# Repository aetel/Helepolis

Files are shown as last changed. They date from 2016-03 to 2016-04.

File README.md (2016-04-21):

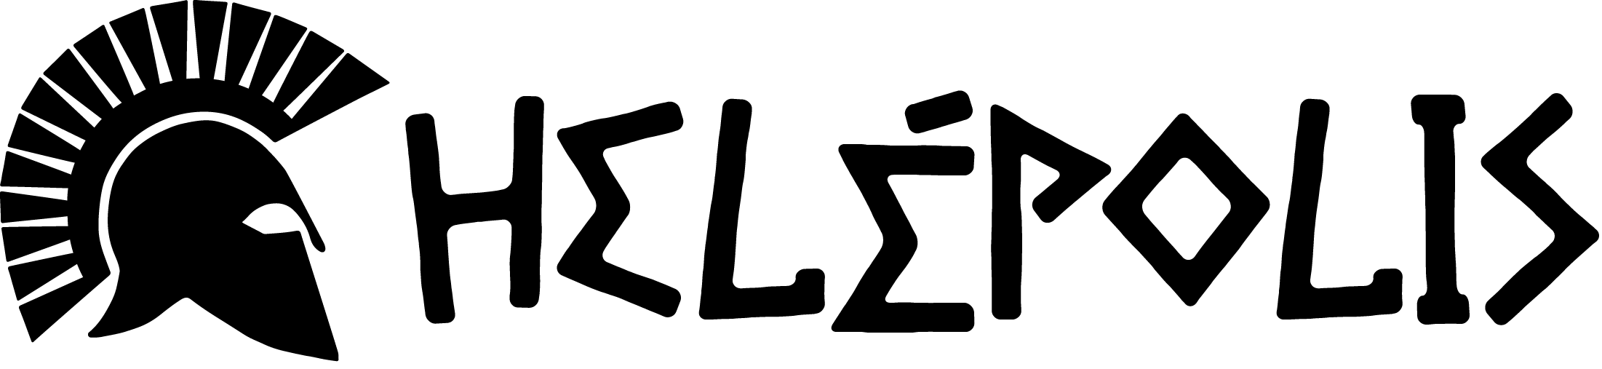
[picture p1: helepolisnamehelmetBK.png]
Helepolis


Helepolis is an **educative** robot for those who want to have their **first contact** with robotics.

It's based around the Arduino platform, using an Arduino Nano as its brain.
It can be programmed to complete numerous tasks such as line following and sumo fighting.

---
### The machine includes:
* An Arduino Nano with ATMega 328p
* SHARP Distance Sensor
* 5 Reflective IR Sensors
* Differential Traction with 2 Pololu Micromotors
* Bluetooth module.
* 2 WS2812 RGB LED
* 4 5mm led
* I2C or SPI Expansion Module Port (intended use is for an ADXL345 3-axis accelerometer)
* Buzzer
* A few switches for general use

---
### In this repository you will find:
* EagleCAD project
<br>&nbsp;&nbsp;Includes the schematic and the PCB files
* TestCode
<br>&nbsp;&nbsp;A program to check all the sensors and actuators are working fine
* ExampleCode
<br>&nbsp;&nbsp;Line follower and sumo bot example program
* Assembly manuals
<br>&nbsp;&nbsp;Guided assembly manuals in English and Spanish
* BoM
<br>&nbsp;&nbsp;Bill of Materials used for the robot

---
### Android app:
You can download the app to control the robot at [Google Play](https://play.google.com/store/apps/details?id=aetel.helepolis), though you may be interested in building or modifying the code available in this repository.

---


Helepolis and its surrounding materials are published under [CC BY-SA 4.0](https://creativecommons.org/licenses/by-sa/4.0/)

Helepolis was designed by [Pablo dMM](https://github.com/PabloDMM "Pablo dMM") for Telecom Electronics Association [AETEL](http://aetel.io), based at the Campus Sur of [Universidad Politécnica de Madrid](http://upm.es).

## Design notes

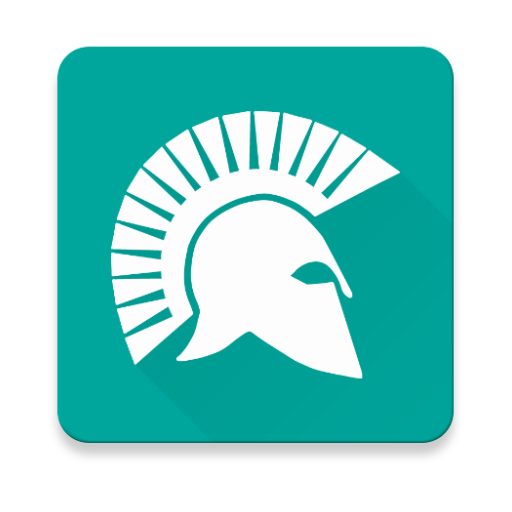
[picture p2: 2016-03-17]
Android project/Helepolis/ic_launcher-web.png

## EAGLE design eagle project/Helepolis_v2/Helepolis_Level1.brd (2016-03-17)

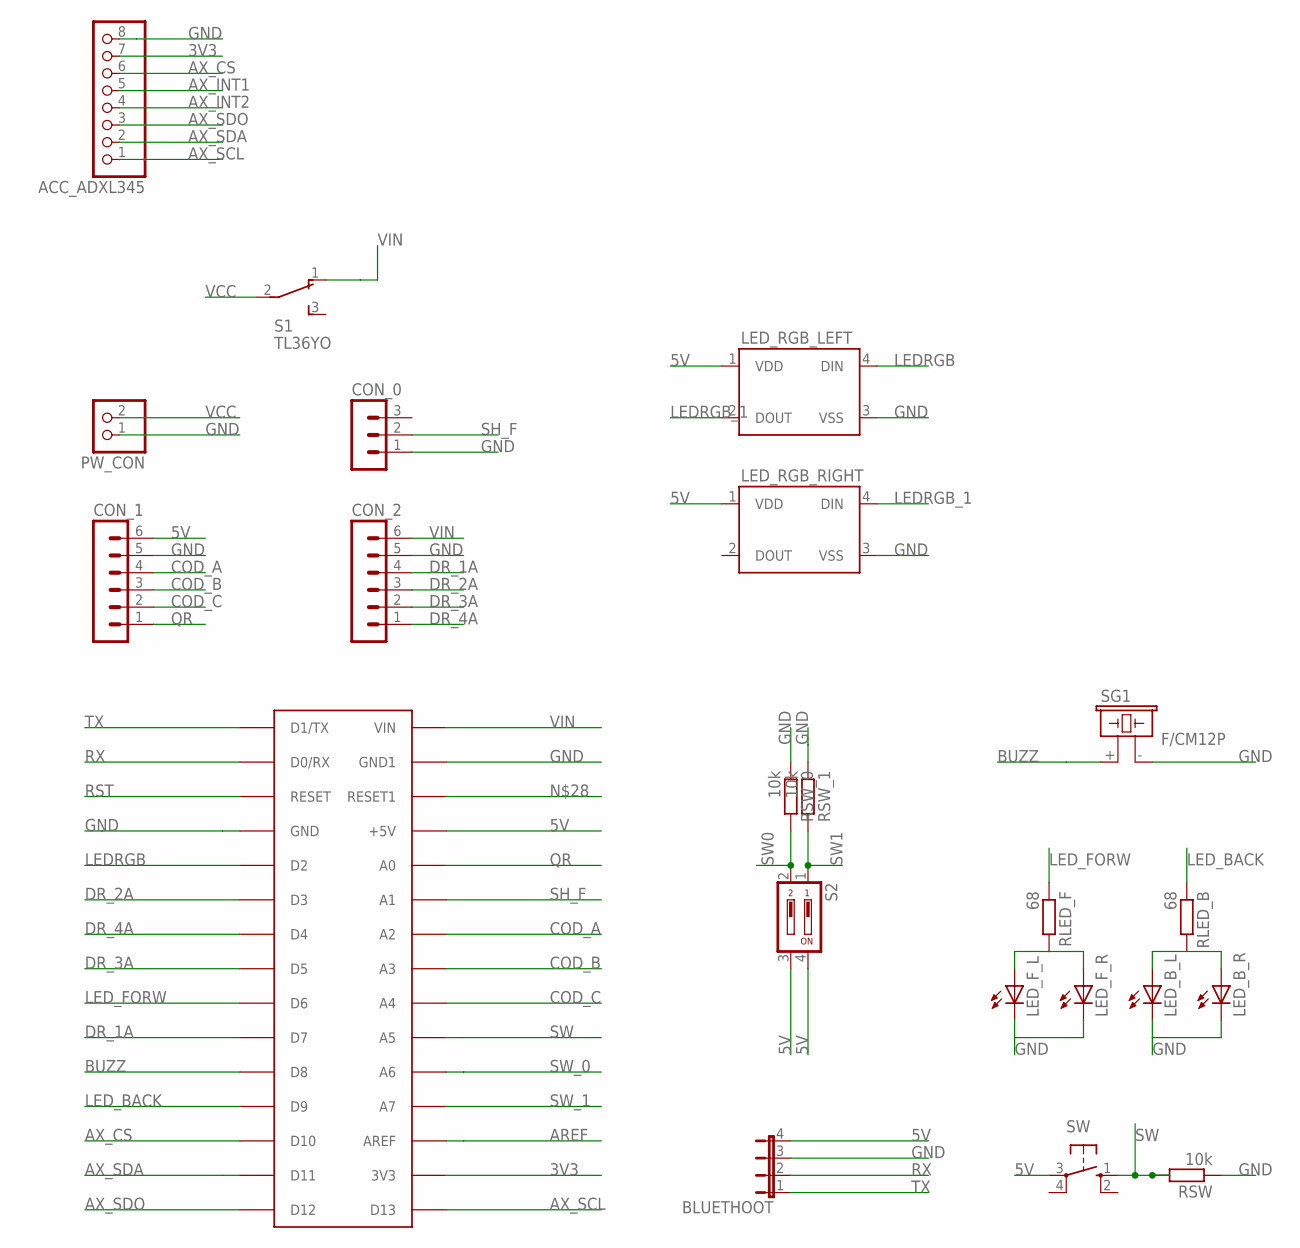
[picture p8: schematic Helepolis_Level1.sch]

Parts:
ACC_ADXL345: PINHD-1X8; 1X08
BLUETHOOT: JP4E; JP4
CON_0: MA03-1
CON_1, CON_2: MA06-1
LED_B_L: LED5MM
LED_B_R: LED5MM
LED_F_L: LED5MM
LED_F_R: LED5MM
LED_RGB_LEFT: WS2812B
LED_RGB_RIGHT: WS2812B
PW_CON: PINHD-1X2; 1X02
RLED_B: 68; R1206
RLED_F: 68; R1206
RSW: 10k; R1206
RSW_0, RSW_1: 10k; R1206
S1: TL36YO; TL3XYO
S2: DP02; DP-02
SG1: F/CM12P
SW: 10-XX; B3F-10XX
U$1: ARDUINONANO; PDIP-32

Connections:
3V3: ACC_ADXL345.7, U$1.3V3
5V: BLUETHOOT.4, CON_1.6, LED_RGB_LEFT.1 (VDD), LED_RGB_RIGHT.1 (VDD), S2.3, S2.4, SW.3, U$1.+5V
AREF: U$1.AREF
AX_CS: ACC_ADXL345.6, U$1.D10
AX_INT1: ACC_ADXL345.5
AX_INT2: ACC_ADXL345.4
AX_SCL: ACC_ADXL345.1, U$1.D13
AX_SDA: ACC_ADXL345.2, U$1.D11
AX_SDO: ACC_ADXL345.3, U$1.D12
BUZZ: SG1.+ (1), U$1.D8
COD_A: CON_1.4, U$1.A2
COD_B: CON_1.3, U$1.A3
COD_C: CON_1.2, U$1.A4
DR_1A: CON_2.4, U$1.D7
DR_2A: CON_2.3, U$1.D3
DR_3A: CON_2.2, U$1.D5
DR_4A: CON_2.1, U$1.D4
GND: ACC_ADXL345.8, BLUETHOOT.3, CON_0.1, CON_1.5, CON_2.5, LED_B_L.K (C), LED_B_R.K (C), LED_F_L.K (C), LED_F_R.K (C), LED_RGB_LEFT.3 (VSS), LED_RGB_RIGHT.3 (VSS), PW_CON.1, RSW.1, RSW_0.1, RSW_1.1, SG1.- (2), U$1.GND, U$1.GND1
LEDRGB: LED_RGB_LEFT.4 (DIN), U$1.D2
LEDRGB_1: LED_RGB_LEFT.2 (DOUT), LED_RGB_RIGHT.4 (DIN)
LED_BACK: RLED_B.1, U$1.D9
LED_FORW: RLED_F.1, U$1.D6
unnamed: LED_F_L.A, LED_F_R.A, RLED_F.2
unnamed: LED_B_L.A, LED_B_R.A, RLED_B.2
QR: CON_1.1, U$1.A0
RST: U$1.RESET
RX: BLUETHOOT.2, U$1.D0/RX
SH_F: CON_0.2, U$1.A1
SW: RSW.2, SW.1 (S), U$1.A5
SW0: RSW_0.2, S2.2
SW1: RSW_1.2, S2.1
SW_0: U$1.A6
SW_1: U$1.A7
TX: BLUETHOOT.1, U$1.D1/TX
VCC: PW_CON.2, S1.2
VIN: CON_2.6, S1.1 (O), U$1.VIN

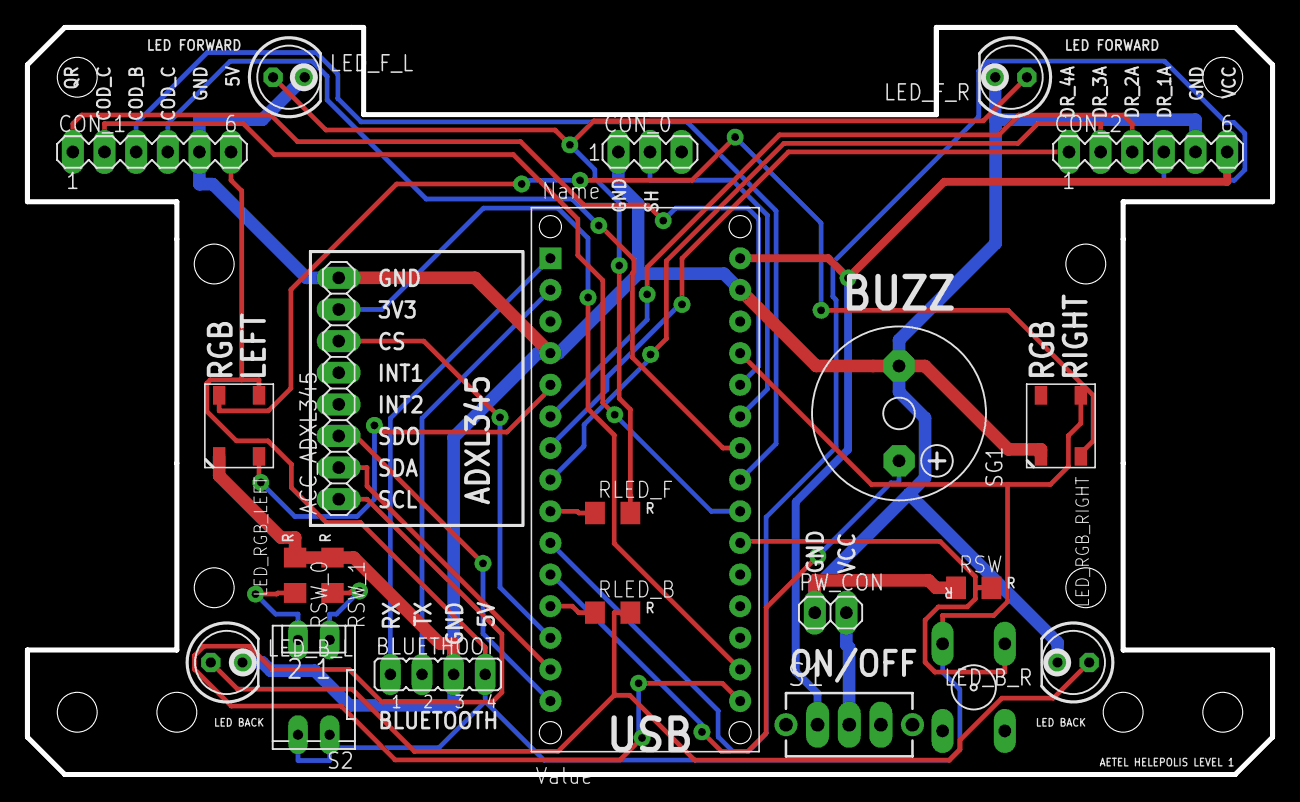
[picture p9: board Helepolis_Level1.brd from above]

Board: 2 copper layers, 100.0 x 60.0 mm, 22 parts (0 on the bottom side), 30 nets.

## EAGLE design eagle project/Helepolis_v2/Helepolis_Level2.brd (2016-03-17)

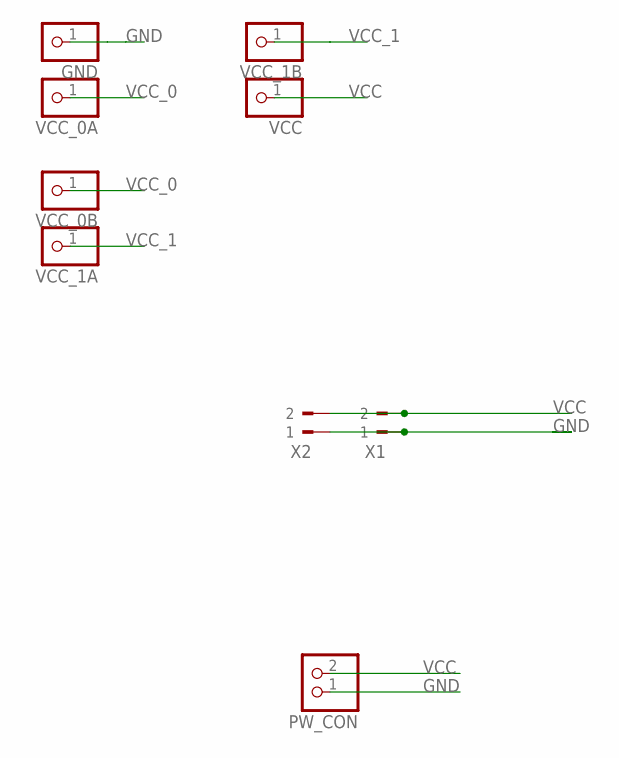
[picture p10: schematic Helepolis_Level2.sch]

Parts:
GND: PINHD-1X1; 1X01
PW_CON: PINHD-1X2; 1X02
VCC: PINHD-1X1; 1X01
VCC_0A, VCC_0B, VCC_1A, VCC_1B: PINHD-1X1; 1X01
X1, X2: 90-2

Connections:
GND: GND.1, PW_CON.1, X1.1, X2.1
VCC: PW_CON.2, VCC.1, X1.2, X2.2
VCC_0: VCC_0A.1, VCC_0B.1
VCC_1: VCC_1A.1, VCC_1B.1

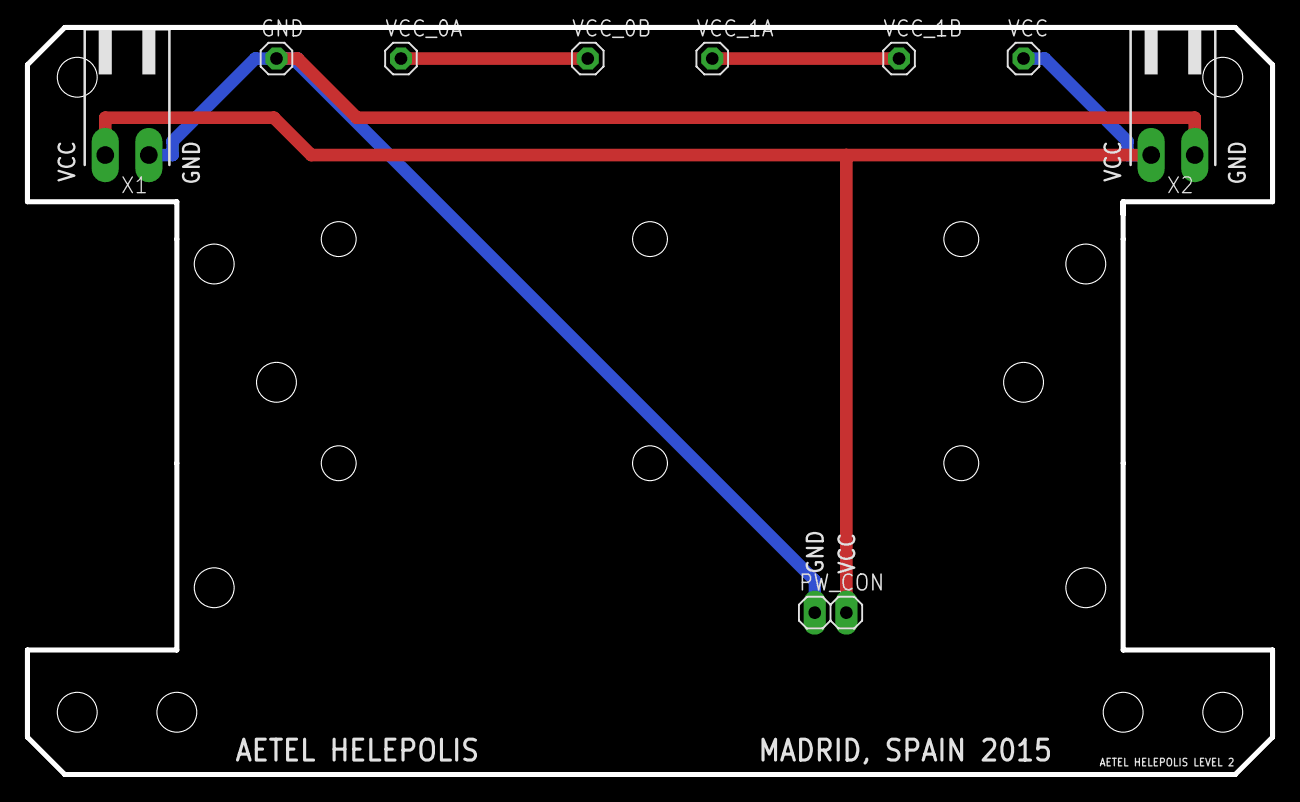
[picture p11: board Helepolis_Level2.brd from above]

Board: 2 copper layers, 100.0 x 60.0 mm, 9 parts (0 on the bottom side), 4 nets.

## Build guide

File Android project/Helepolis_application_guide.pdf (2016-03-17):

# AETEL’S HELEPOLIS

# APPLICATION GUIDE

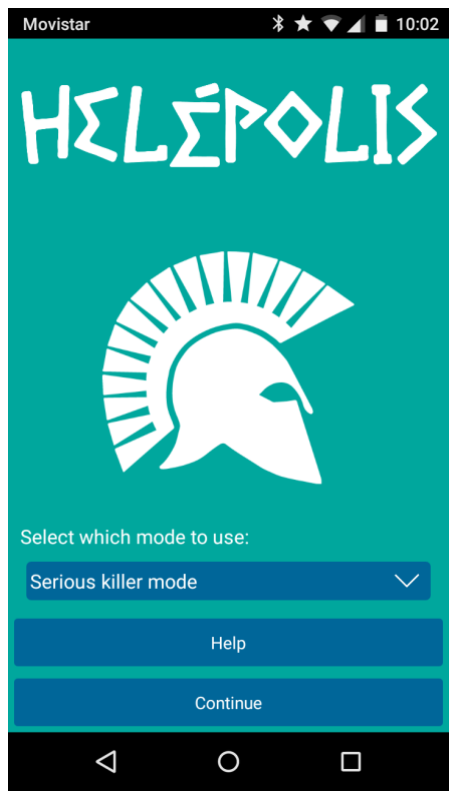
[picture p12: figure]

# Javier Martínez Arrieta

# martinezarrietajavier@gmail.com

### Contents

### Abstract

This is a short guide to be used as guidance in order to know how to clone the project in order to adapt for custom purposes or installing the Helepolis Android application.

### About the author

The application has been developed by Javier Martínez Arrieta. The icon of the application and the images shown in the main screen were designed by Ricardo Sanz Retuerta (ricardosanz1b@gmail.com)

### License

This project is licensed under Creative Commons Attribution-Non Commercial-Share Alike 4.0 International (CC BY-NC-SA 4.0). According to this license you are free to:

Share — copy and redistribute the material in any medium or format.

Adapt — remix, transform, and build upon the material.

The licensor cannot revoke these freedoms as long as you follow the license terms.

Complete information about this license can be found at: https://creativecommons.org/licenses/by-nc-sa/4.0/legalcode

### Cloning into a local folder

### Cloning using git commands

In case of being a Windows user, open Git Shell (available at in case you do not have it installed) and type ‘git clone https://github.com/Javierma/Helepolis’

If it goes as expected, you should be able to have a new folder called ‘Helepolis’ under the folder you are (C:\Users\Javier\Documents\GitHub in this example).

In | case | of | being | a | Linux | user, | open | a | terminal | and | type | ‘git | clone
https://github.com/Javierma/Helepolis’ (if git is not installed, run sudo apt-get install git)

If it goes as expected, you should be able to have a new folder called ‘Helepolis’ under the folder you are (C:\Users\Javier\Documents\GitHub in this example).

### Cloning ‘graphically’

There is as well an option to clone the project in your computer without using git commands. In this case, click the ‘Download ZIP’ button:

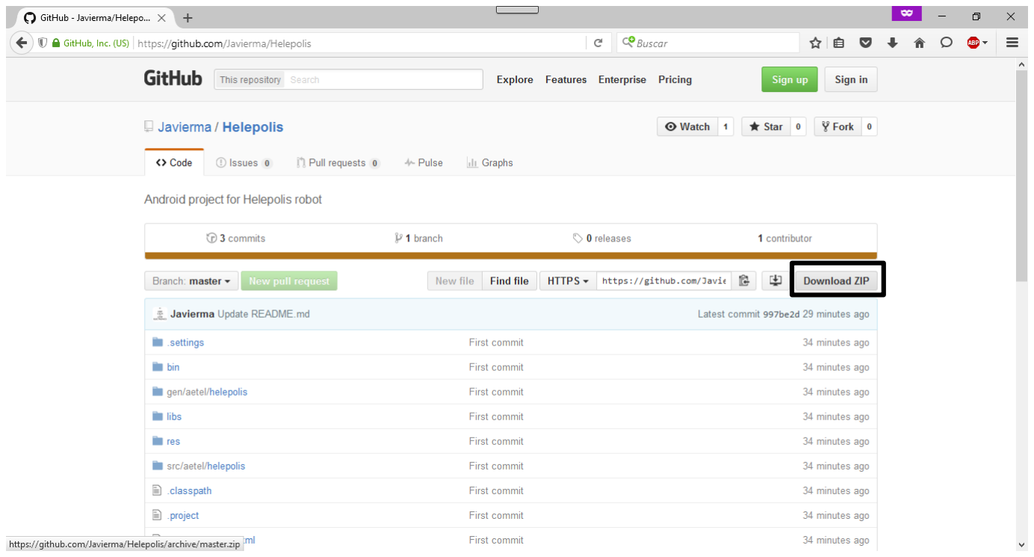
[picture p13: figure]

### Importing as an Eclipse project

If your interest is to modify the project to adjust it to your custom needs or just desire to have a look at it, you can easily import the project to modify it. For that purpose, open Eclipse and go to File->Import…

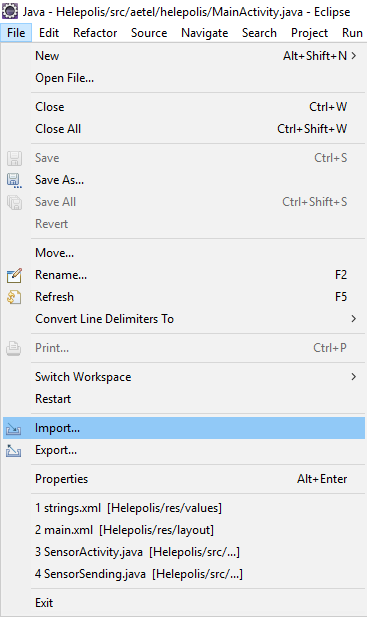
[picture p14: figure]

Select the option ‘Existing Android Code Into Workspace’ and click on ‘Next’ button:

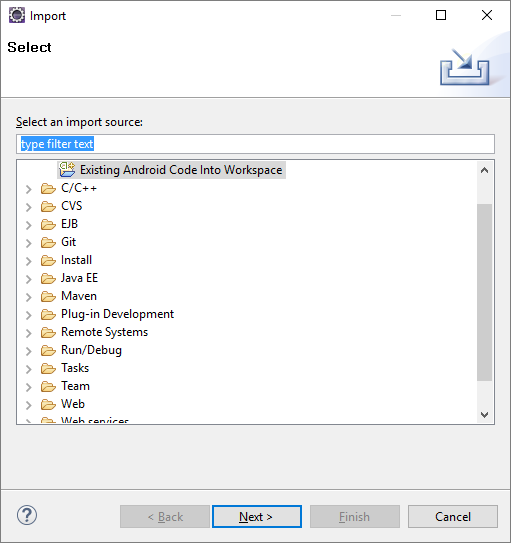
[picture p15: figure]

Click on ‘Browse’ button to search for ‘Helepolis’ folder. Then, select it as project to import and click on ‘Finish’.

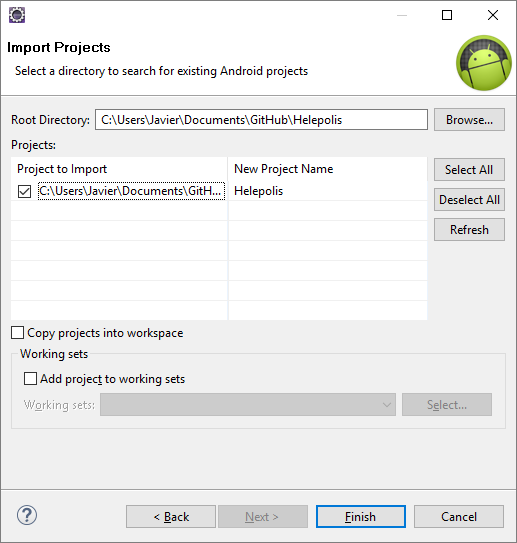
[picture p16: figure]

### Installing the signed APK file

In case of installing the APK file into your mobile phone, you can run it from Eclipse and, if the settings are correct, it will be installed in your mobile phone. In case of having security problems for trying to install the application, you can try to install a signed apk file available under the ‘bin’ folder of the project (file called ‘Helepolis_signed.apk’).

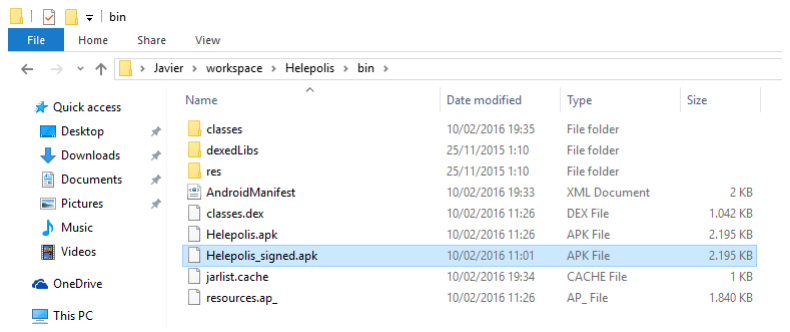
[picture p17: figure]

With the file selected, copy it into you mobile phone. To do that, a device should appear on the left side on the window:

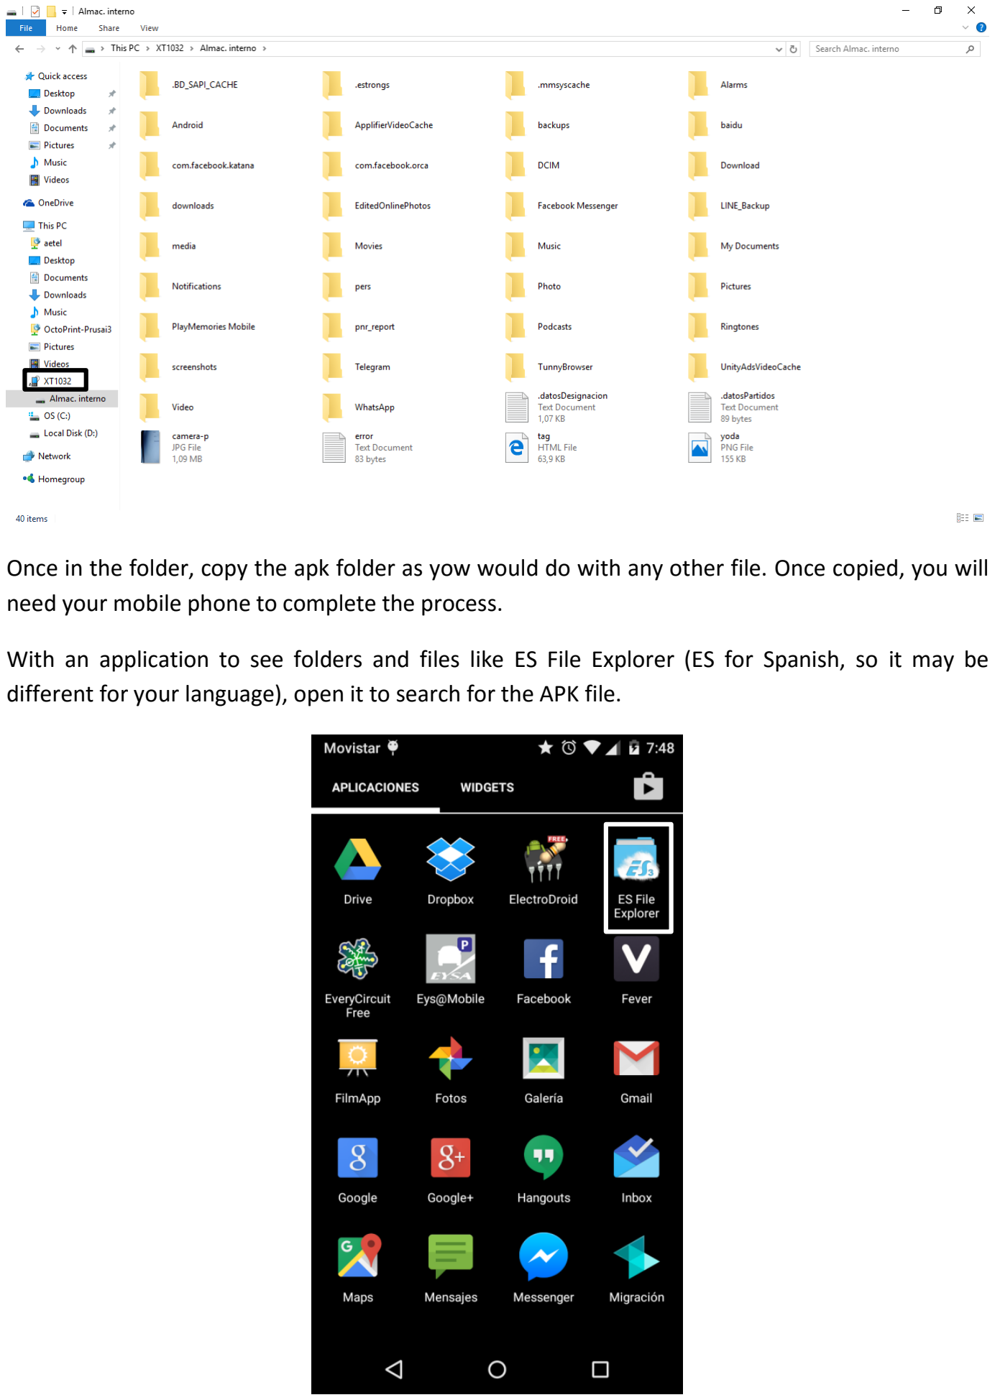
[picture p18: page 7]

Once in the folder, copy the apk folder as yow would do with any other file. Once copied, you will need your mobile phone to complete the process.

With an application to see folders and files like ES File Explorer (ES for Spanish, so it may be different for your language), open it to search for the APK file.

Now look for ‘Helepolis_signed.apk’ file that you just copied an click on it.

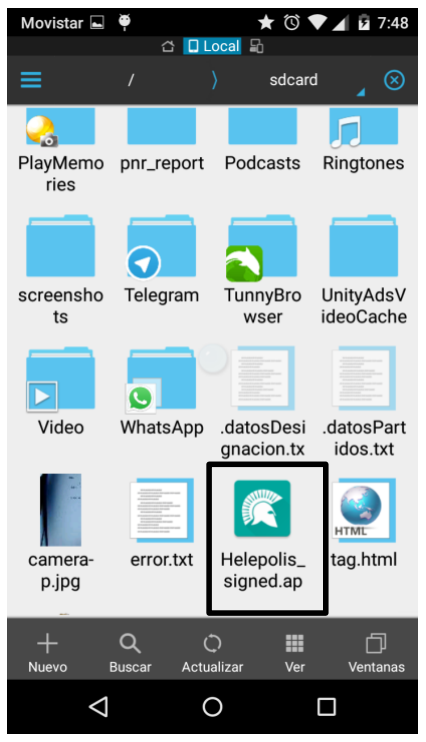
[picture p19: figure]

Now you can see that on the bottom-right part there is an install option. Click on it to install the application.

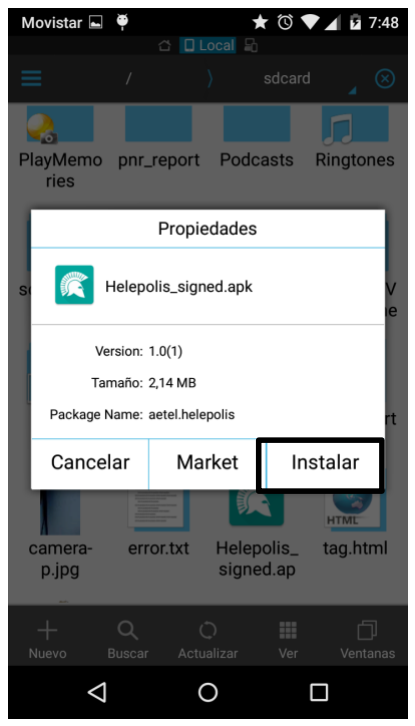
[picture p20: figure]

You will see information related with security options. To install the application, click on install (‘Instalar’ in Spanish language).

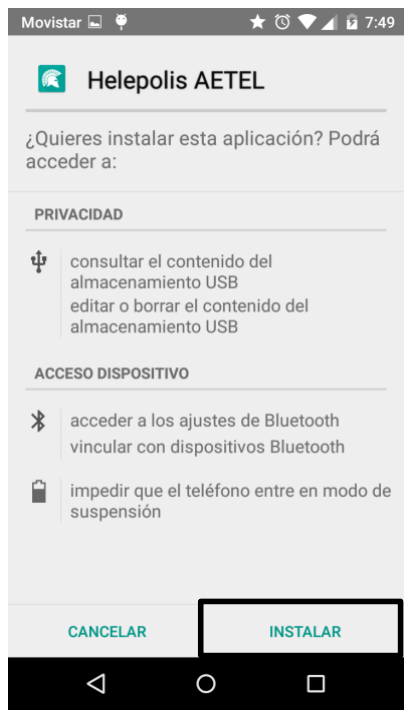
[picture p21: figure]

If the installation run correctly, you will see something like the following, indicating that the installation process was correct:

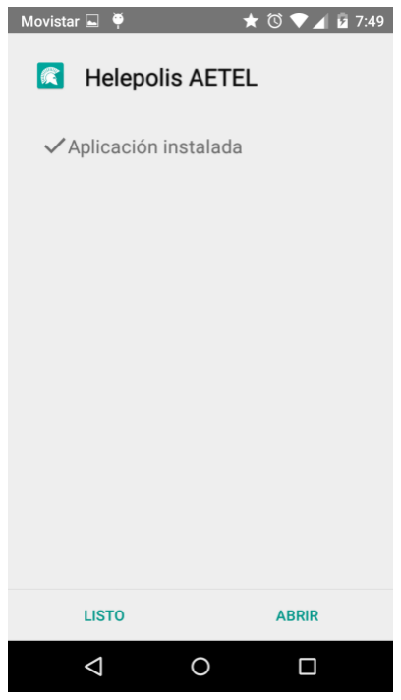
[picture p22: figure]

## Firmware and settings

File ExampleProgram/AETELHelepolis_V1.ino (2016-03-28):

/*
AETEL Helepolis
Description: Software for the AETEL Helepolis. It covers 4 modes
  Sumobot WB Mode: The Sumobot Mode programs the AETEL Helepolis to act as a Sumobot. The aim of a Sumobot robot is to Search&Destroy a rival Sumobot.(White Border) 
  Sumobot BB Mode: The Sumobot Mode programs the AETEL Helepolis to act as a Sumobot. The aim of a Sumobot robot is to Search&Destroy a rival Sumobot.(Black Border)
  Line Follower Mode: The Line Follower Mode programs the AETEL Helepolis to follow a Black line.
  Bluetooth Mode: The Bluetooth Mode programs the AETEL Helepolis to act as a Bluetooth remote controlled device.
       
Authors: Pablo de Miguel Morales (Pablodmm.isp@gmail.com)
         Javier Martinez Arrieta
         
Release: 18.11.2015
*/

#include <Adafruit_NeoPixel.h>
#include <Wire.h>
#include <Adafruit_Sensor.h>
#include <Adafruit_ADXL345_U.h>

// Pin Definitions
#define MUL_A 19
#define MUL_B 18
#define MUL_C 17
#define MOT_A_1 3
#define MOT_A_2 7
#define MOT_B_1 5
#define MOT_B_2 4
#define QRIR 7
#define SHARP 6
#define SW 16
#define SW_1 14
#define SW_0 15
#define BUZZ 8
#define LED_RGB 2
#define LED_FORW 6
#define LED_BACK 9
#define AX_CS 10
#define AX_SDA 11
#define AX_SDO 12
#define AX_SCL 13

const int borderThr = 900;
const int distanceThr = 300;
int inMSS[6];         // incoming serial byte
int speedA = 0;
int speedB = 0;
int ledRv = 0;
int ledGv = 0;
int ledBv = 0;
int ledFORWv = 0;
int ledBACKv = 0;
int dirA = 1;
int dirB = 1;
int QRVal[5] = {0,0,0,0,0};
int ADXVal[3] = {0,0,0};
int CountQR = 0;
boolean borderDetected = 0; // Border Detected Flag
boolean rivalDetected = 0; // Rival Detected Flag
boolean lastDir = 0; // LF Last Direction Flag
int stateSumo=0; // Sumobot Mode State
int stateLineFollower=0; // LineFollower Mode State
int Mode=0; // General Working Mode
Adafruit_NeoPixel strip = Adafruit_NeoPixel(2, LED_RGB, NEO_GRB + NEO_KHZ800);
//Adafruit_ADXL345_Unified ADX = Adafruit_ADXL345_Unified(12345);

void setup(){
  Serial.begin(9600);
  pinMode(LED_FORW, OUTPUT);
  pinMode(LED_BACK, OUTPUT);
  pinMode(MUL_A, OUTPUT);
  pinMode(MUL_B, OUTPUT);
  pinMode(MUL_C, OUTPUT);
  pinMode(MOT_A_1, OUTPUT);
  pinMode(MOT_A_2, OUTPUT);
  pinMode(MOT_B_1, OUTPUT);
  pinMode(MOT_B_2, OUTPUT);
  pinMode(SW, INPUT);
  pinMode(SW_0, INPUT);
  pinMode(SW_1, INPUT);
  digitalWrite(LED_FORW,LOW);
  digitalWrite(LED_BACK,LOW);
  strip.begin(); // LED RGB Initialization
  strip.show(); // LED RGB OFF
  //ADX.setRange(ADXL345_RANGE_16_G); // Acc Initialization
  // Mode Selection
  if(digitalRead(SW_0)){
    if (digitalRead(SW_1)){
      Mode = 0; // Sumobot Mode Black Border
    }else{
      Mode = 1; // Sumobot Mode White Border
    }
  }else{
    if (digitalRead(SW_1)){
      Mode = 2; // Line Follower Mode
    }else{
      Mode = 3; // Bluetooth Controlled Mode
    }
  }
}

void loop(){
  switch(Mode){
    case 0: // Sumobot Mode Black Border
      SumobotMode();
      ReadIRSensor();
      ReadDistanceSensor();
      break;
    case 1: // Sumobot Mode White Border
      SumobotMode();
      ReadIRSensor();
      ReadDistanceSensor();
      break;
    case 2: // Line Follower Mode
      LineFollowerMode();
      ReadIRSensor();
      ReadDistanceSensor();
      break;
    case 3: // Bluetooth Controlled Mode
      BluetoothMode();
      break;
 }
}

/* Function: motorControl(int motADir, int motASpeed, int motBDir, int motBSpeed)
   This Function controls the motors through 2 directions and 2 speeds [0:255]
*/
void motorControl(int motADir, int motASpeed, int motBDir, int motBSpeed){
  if(motADir==1)
  { 
    digitalWrite(MOT_A_1, HIGH);
    analogWrite(MOT_A_2, (255 - motASpeed));
  }else{
    digitalWrite(MOT_A_1, LOW);
    analogWrite(MOT_A_2, motASpeed);
  } 
  if(motBDir==1)
  { 
    digitalWrite(MOT_B_1, HIGH);
    analogWrite(MOT_B_2, (255 - motBSpeed));
  }else{
    digitalWrite(MOT_B_1, LOW);
    analogWrite(MOT_B_2, motASpeed);
  }
}

/* Function: RGBLedControl(int valR_R, int valG_R, int valB_R, int valR_L, int valG_L, int valB_L)
   This Function controls the two RGB WS2812B LED
*/
void RGBLedControl(int valR_R, int valG_R, int valB_R, int valR_L, int valG_L, int valB_L)
{
  strip.setPixelColor(0,valR_R,valG_R,valB_R);
  strip.setPixelColor(1,valR_L,valG_L,valB_L);
  strip.show();
}

/* Function: LedControl(int valFORW, int valBACK)
   This Function controls the four LEDs in pair (one pair FORWARD, on pair BACK)
*/
void LedControl(int valFORW, int valBACK)
{
  analogWrite(LED_FORW, valFORW);
  if(valBACK==0){digitalWrite(LED_BACK,LOW);}else{digitalWrite(LED_BACK,HIGH);}
}

void blueTooth(void)
{
  if(Serial.available()>0)
  {
    int inByte;
    for(int i = 0; i<10; i++)
    {
      inByte=Serial.read();
      inMSS[i]=inByte;
      //if(inByte!='#'){break;}
    }
  }
}

void inMSSread(void)
{
  if(inMSS[2]=='1') // Detects if it is an analog order.
  {
    int speedM;
    if(inMSS[9]=='#'){speedM=(inMSS[7]*10+inMSS[8]);}
    else{speedM=(inMSS[7]*100+inMSS[8]*10+inMSS[9]);}
    if((inMSS[4]=='0')&&(inMSS[5]=='9'))
    {
      speedB=speedM;
    }
    if((inMSS[4]=='1')&&(inMSS[5]=='1'))
    {
      speedA=speedM;
    }
  }
}

/* Function: ReadIRSensor()
   This Function controls the reading of the five IRSensors and activates border detecting flags
*/
void ReadIRSensor()
{
  borderDetected = 0; // Border Detected Flag Reset
  for (int mulCount=0; mulCount<=4; mulCount++) { // QRE1113 Lecture Sensor through 74HC4051 Multiplexer
    // Entry channel selection for 74HC4051
    int cA = mulCount & 0x01;   
    int cB = (mulCount>>1) & 0x01;     
    int cC = (mulCount>>2) & 0x01;    
    digitalWrite(MUL_A, cA);
    digitalWrite(MUL_B, cB);
    digitalWrite(MUL_C, cC);
    // Data analisys and process
    QRVal[mulCount] = analogRead(QRIR);
    switch(Mode){
      case 0: // Sumobot Mode Black Border
        if(QRVal[mulCount]<borderThr){ // Border Detected
        borderDetected = 1;} // Border Detected Flag Set Up
        break;
      case 1: // Sumobot Mode White Border
        if(QRVal[mulCount]>borderThr){ // Border Detected
        borderDetected = 1;} // Border Detected Flag Set Up
        break;
      case 2: // Line Follower Mode
        if(QRVal[mulCount]>borderThr){ // Border Detected
        borderDetected = 1;} // Border Detected Flag Set Up
        break;
    }
  }
}

/* Function:  ReadDistanceSensor()
   This Function controls the reading of SHARP distance sensor
*/
void ReadDistanceSensor()
{
  rivalDetected = 0; // Rival Detected Flag Reset
  if(analogRead(SHARP)>distanceThr){
    rivalDetected = 1;
  }
}


/* Function:  ADXRead(void)
   This Function controls the ADX345 Accelerometer
*/
/*
void ADXRead(void)
{
  sensors_event_t event; 
  ADX.getEvent(&event);
  ADXVal[0] = event.acceleration.x;
  ADXVal[1] = event.acceleration.y;
  ADXVal[2] = event.acceleration.z;
}*/

/* Function:  SumobotMode()
   This Function controls the Sumobot Mode
*/
void SumobotMode(){ // Sumobot Behaviour Mode (Both B/W)
  switch(stateSumo){
    case 0: // Relax
      motorControl(0,0,0,0); // Motors OFF
      LedControl(0,0); // F/B LEDs OFF
      RGBLedControl(0,255,255,0,255,255); // COLOR GB
      if(digitalRead(SW)){ // START SWITCH PRESSED COUNTDOWN 
        stateSumo=1; // go to SB Search State
        for(int i = 0; i<4; i++){
          tone(BUZZ,(160+(i*500)));
          RGBLedControl((50+(i*40)),(50+(i*40)),(50+(i*40)),(50+(i*40)),(50+(i*40)),(50+(i*40))); // Light Blink Progression
          delay(500);
          noTone(BUZZ);
          RGBLedControl(0,0,0,0,0,0);
          delay(500);
         }
       }
       break;
     case 1: // Search
       motorControl(1,200,0,200); // Motors SPIN
       LedControl(255,255); // F/B LEDs ON
       RGBLedControl(255,0,255,255,0,255); // COLOR RB
       // SB State Transition
       if(digitalRead(SW)){stateSumo=0;} // go to SB Relax State
       else if(borderDetected){stateSumo=2;} // go to SB BorderAvoid State
       else if(rivalDetected){stateSumo=3;} // go to SB Attack State
       break;
     case 2: // BorderAvoid
       motorControl(0,200,0,200); // Motors BACK
       LedControl(0,255); // F/B LEDs ON
       RGBLedControl(255,0,0,255,0,0); // COLOR R
       delay(200); // Time
       // SB State Transition
       if(digitalRead(SW)){stateSumo=0;} // go to SB Relax State
       if(!borderDetected){stateSumo=1;} // go to SB BorderAvoid State
       break;
     case 3: // Attack
       motorControl(1,200,1,200); // Motors FORWARD
       LedControl(255,0); // F/B LEDs ON
       RGBLedControl(0,255,0,0,255,0); // COLOR G
       delay(100); // Time
       // SB State Transition
       if(digitalRead(SW)){stateSumo=0;} // go to SB Relax State
       else if(borderDetected){stateSumo=2;} // go to SB BorderAvoid State
       else if(!rivalDetected){stateSumo=1;} // go to SB Search State
       break;
  }
}

/* Function:  LineFollowerMode()
   This Function controls the Line Follower Mode
*/
void LineFollowerMode(){ // Line Follower Behaviour Mode
  
  int speedLeft = 0; // Speed for Left Motor
  int speedRight = 0; // Speed for Right Motor
  switch(stateLineFollower){
  case (0): // Relax
    delay(500);
    motorControl(0,0,0,0); // Motors OFF
    LedControl(0,0); // F/B LEDs OFF
    RGBLedControl(0,255,255,0,255,255); // COLOR GB
    if(digitalRead(SW)){ // START SWITCH PRESSED COUNTDOWN 
      stateLineFollower=1; // go to LN LineSearch State
      for(int i = 0; i<4; i++){
        tone(BUZZ,(160+(i*500)));
        RGBLedControl((50+(i*40)),(50+(i*40)),(50+(i*40)),(50+(i*40)),(50+(i*40)),(50+(i*40))); // Light Blink Progression
        delay(500);
        noTone(BUZZ);
        RGBLedControl(0,0,0,0,0,0);
        delay(500);
       }
     }
     break;
  case(1): // LineSearch
     switch(lastDir){
       case(0):
          motorControl(0,130,1,130); // Motors SPIN
          break;
       case(1):
          motorControl(1,130,0,130); // Motors SPIN
          break;
      }
     RGBLedControl(255,0,0,255,0,0); // COLOR R
     // LN State Transition
     if(digitalRead(SW)){stateLineFollower=0;} // go to LN Relax State
     else if(borderDetected){stateLineFollower=2;} // go to LN InLine State  
     break;
  case (2):
     if(QRVal[2] > borderThr){
       speedLeft = 150; // Base Speed
       speedRight = 150; // Base Speed
       if (QRVal[0] > borderThr){speedRight+=50;}
       if (QRVal[1] > borderThr){speedLeft+=50;}
       motorControl(1,speedLeft,1,speedRight);
       RGBLedControl(0,255,speedLeft,0,255,speedRight); // COLOR G Variable
     }else if(QRVal[3] > borderThr){
       speedLeft = 100; // Base Speed
       speedRight = 150; // Base Speed
       motorControl(1,speedLeft,1,speedRight);
       RGBLedControl(0,0,255,0,0,255); // COLOR B
       lastDir = 0;
     }else if(QRVal[4] > borderThr){
       speedLeft = 150; // Base Speed
       speedRight = 100; // Base Speed
       motorControl(1,speedLeft,1,speedRight);
       RGBLedControl(0,0,0,0,0,255); // COLOR B
       lastDir = 1;
     }
    // LN State Transition
    if(digitalRead(SW)){stateLineFollower=0;} // go to LN Relax State
    else if(!borderDetected){stateLineFollower=1;} // go to LN LineSearch State
    break;
  }  
}

/* Function:  BluetoothMode()()
   This Function controls the Bluetooth controlled device Mode
*/
void BluetoothMode()
{
  //UART sends and receives byte by byte, so when calling Serial.read() 1 byte is read.
//As UART is asynchronous, timer cannot be used to know when all data is received, but it would be useful to know about connection loss.
//Wait until all necessary data is available to avoid problems such as reading wrong values (e.g.assining frontLedsMode value to backLedsMode value)
/*    while(Serial.available()!=13);
    dir=Serial.read();
    veloIzq=Serial.read();
    veloDer=Serial.read();
    frontLedsMode=Serial.read();
    backLedsMode=Serial.read();
    leftRGBMode=Serial.read();
    valueRed1=Serial.read();
    valueGreen1=Serial.read();
    valueBlue1=Serial.read();
    rightRGBMode=Serial.read();
    valueRed2=Serial.read();
    valueGreen2=Serial.read();
    valueBlue2=Serial.read();
    Serial.write(1010);*///Could be anything, it is to assure that no new data will be sent from Android app
    //functions
    //No delay is required since it is done in the Android application
}
  
             

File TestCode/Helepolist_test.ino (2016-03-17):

/*Copyright 2016 AETEL
The AETEL Helepolis is released under an Attributtion-ShareAlike 4.0 International (CC BY-SA 4.0) . Therefore, anyone is free to:
•  Share – Copy and redistribute the material in any medium or format.
•  Adapt – Remix, transform, and build upon the material for any purpose, even commercially.
*/
//Code written by Javier Martínez Arrieta to check that all parts of Helepolis work

#include <Adafruit_NeoPixel.h> 
#include <ctype.h>

#define LED_AUTOMATIC 2
#define LED_MANUAL_OFF 0
#define LED_MANUAL_ON 1
#define FORWARD 1
#define BACKWARDS 0
#define STOP 2

#define QRE A7
#define MOT_A_1 7
#define MOT_A_2 3
#define MOT_B_1 4
#define MOT_B_2 5
#define QR_INT 2
#define SHARP_F A6
#define SW 16
#define SW_1 14
#define SW_0 15
#define COD_A 19
#define COD_B 18
#define COD_C 17
#define BUZZ 8
#define LED_FORW 6
#define LED_BACK 9
#define NUMPIXELS 2

#define THRESHOLD_DISTANCE 400
#define COWARD_MODE 0
#define SERIAL_KILLER_MODE 1
#define MAX_TIME 3000

int robot_mode;
int dir=STOP,leftSpeed=255,rightSpeed=255,frontLedsMode=0,backLedsMode=0,leftRGBMode=1,leftRed=255,leftGreen=255,leftBlue=255,rightRGBMode=1,righttRed=255,rightGreen=255,rightBlue=255;

//Creates an object to control RGB leds
Adafruit_NeoPixel pixels = Adafruit_NeoPixel(NUMPIXELS, QR_INT, NEO_GRB + NEO_KHZ800);

//Method called when Arduino is switched on
void setup()
{
  //Starts serial to allow Bluetooth communication
  Serial.begin(9600); 
  //Starts RGB leds control
  pixels.begin();
}

int count=0;

//Method called after setup is done. This is equivalent to while(true) or while(1)
void loop()
{ 
    Serial.println("Helepolis test, which will check if the different parts work correctly\nPress the switch to start");
   //Check if switch is pressed. You will not be able to continue if it is not pressed
   while(digitalRead(SW)!=1);

   delay(100);
   Serial.println("Checking sharp distance sensor. Move your hand or an object to check if value changes. When checked, press the switch");
   //Check that distance is read correctly. Open Serial Monitor and check that values changes when for example you put your hand at different distances
   int count=0;
   while(digitalRead(SW)!=1)
   {
      Serial.println(analogRead(SHARP_F));
      delay(100);
   }

   Serial.println("\nCheking microswitch. Put on or off to check that value changes (on->1, off->0). When checked, press the switch");
   //Check microswitch values. Make changes for a few seconds to check that all possible values are correctly read
   int sw0,sw1;
   delay(100);
   while(digitalRead(SW)!=1)
   {
      sw0=digitalRead(SW_0);
      sw1=digitalRead(SW_1);
      String string="SW0: ";
      string=string+ sw0;
      string=string + "\tSW1: ";
      string=string+ sw1; 
      Serial.println(string);  
      delay(500);
   }

   Serial.println("\nCheck front and back leds. Both should be on.  When checked, press the switch");
   delay(1000);
   while(digitalRead(SW)!=1)
   {
      //Check that front and back leds light correctly
      digitalWrite(LED_FORW,HIGH);
      digitalWrite(LED_BACK,HIGH);
   }

    Serial.println("Switching off leds...");
   //Turn leds off
   digitalWrite(LED_FORW,LOW);
   digitalWrite(LED_BACK,LOW);

   Serial.println("\nBuzzer should be sounding at this moment");
   //Check buzzer. Make it sound for 2 seconds
   analogWrite(BUZZ,255);
   delay(2000);

   //Silence again
   analogWrite(BUZZ,0);

   Serial.println("\nCheking RGB LEDS. Both should light red, green and blue. To start checking, press the button");
   //Check RGB leds, making sure all colours light. The order will be red, green and blue
    while(digitalRead(SW)!=1);
   Serial.println("Lighting red");
    pixels.setPixelColor(0, pixels.Color(255,0,0));
    pixels.setPixelColor(1, pixels.Color(255,0,0));    
    pixels.show();    
    delay(2000);

    Serial.println("Lighting green");
    pixels.setPixelColor(0, pixels.Color(0,255,0));
    pixels.setPixelColor(1, pixels.Color(0,255,0));    
    pixels.show();
    delay(2000);

    Serial.println("Lighting blue");
    pixels.setPixelColor(0, pixels.Color(0,0,255));
    pixels.setPixelColor(1, pixels.Color(0,0,255));    
    pixels.show();   
    delay(2000);
    
    //Switch all colours off
    pixels.setPixelColor(0, pixels.Color(0,0,0));
    pixels.setPixelColor(1, pixels.Color(0,0,0));    
    pixels.show(); 

    Serial.println("\nCheck motors. They should move in both directions, stopping in about 10 seconds. To start checking, press the switch");
    while(digitalRead(SW)!=1)

    //Check motors
    motorControl(FORWARD,255,FORWARD,255);
    delay(5000);
    motorControl(BACKWARDS,255,BACKWARDS,255);
    delay(5000);
    //If properly programmed, PWM value does not matter to stop
    motorControl(STOP,100,STOP,100);
    delay(5000);

    Serial.println("\nChecking white/black sensors. Move the vehicle to check that sensor's value changes when it is above the black line. To start checking, press the switch");
    while(digitalRead(SW)!=1);
    for(count=0;count<50;count++)
    {
        if(count==0)
        {
            Serial.println("Reading QRE0");
        }
        if(count==10)
        {
            Serial.println("Reading QRE1");
        }
        if(count==20)
        {
            Serial.println("Reading QRE2");
        }
        if(count==30)
        {
            Serial.println("Reading QRE3");
        }
        if(count==40)
        {
            Serial.println("Reading QRE4");
        }
        if(count<10)
        {
            read_black_white(0);
        }
        else
        {
            if(count>=10 && count <20)
            {
                read_black_white(1);          
            }
            else
            {
                if(count>=20 && count <30)
                {
                    read_black_white(2);
                }
                else
                {
                    if(count>=30 && count <40)
                    {
                        read_black_white(3);
                    }
                    else
                    {
                        if(count>=40 && count <50)
                        {
                            read_black_white(4);
                        }
                    }
                }
            }  
        }
        delay(1000);
    }
}
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

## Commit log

2016-03-17 Added guides, Android code and eagle project
    [Helepolis_Level0.dsn, Helepolis_Level0.sch, Helepolis_Level1.brd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]
2016-03-28 Moved some files into folders
    …also added CC badge to readme.md
2016-04-21 Solved problems with Bluetooth mode
    [AETELHelepolis_V1.ino]

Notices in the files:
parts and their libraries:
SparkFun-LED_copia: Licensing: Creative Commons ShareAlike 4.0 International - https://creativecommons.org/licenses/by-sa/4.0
